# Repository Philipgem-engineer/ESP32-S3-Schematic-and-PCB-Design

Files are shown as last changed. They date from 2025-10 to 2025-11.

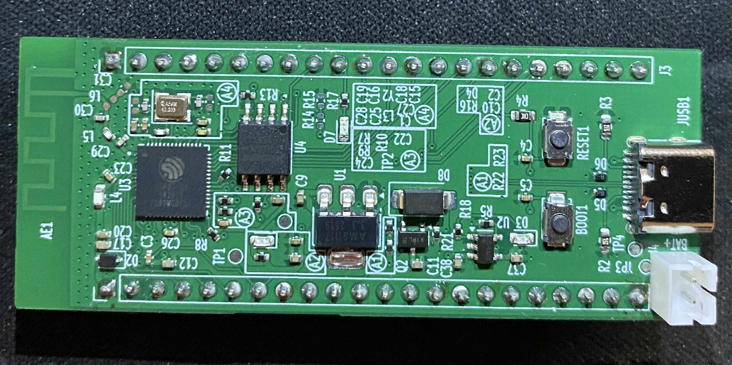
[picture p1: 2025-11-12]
ESP32-S3 Project/Media/ESP32-S3_Front_2.jpg

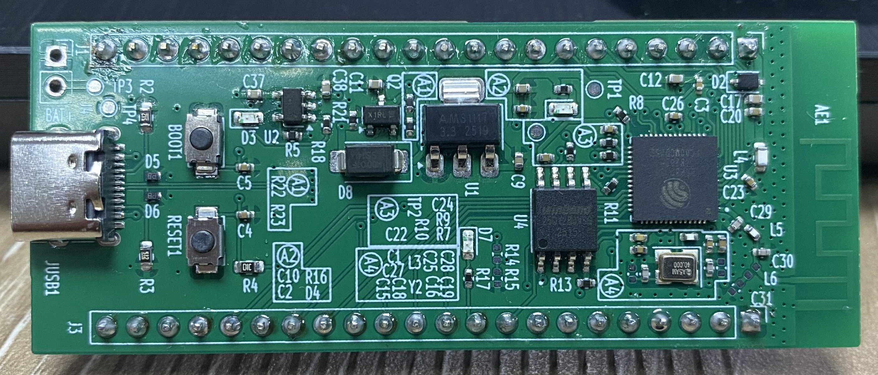
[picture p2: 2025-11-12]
ESP32-S3 Project/Media/ESP32-S3_Front.jpg

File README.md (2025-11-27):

# 🧠 ESP32-S3 – Schematic and PCB Design

This repository contains a custom hardware of an ESP32-S3 microcontroller dev board.
It includes the complete schematic and PCB layout, featuring essential supporting circuits.

##  Features
- ⚡ LDO Voltage Regulator – Provides a stable supply for the ESP32-S3 and peripherals
- 🔋 Battery Charging Circuit – Supports rechargeable lithium battery input
- 💾 Flash Memory – Enables program storage capacity
- 🧩 ESP32-S3 System-on-Chip – Dual-core processor with integrated Wi-Fi and Bluetooth
- ⏱️ Crystal Oscillator – Ensures precise clock timing for system stability
- 📡 Antenna & Antenna Matching Circuit – Integrated in PCB for Wi-Fi/Bluetooth connectivity

##  Tools Used
-  Schematic & PCB Design: KiCad
-  Component Library: LCSC
-  PCB Fabrication: JLCPCB

##  Schematic





##  PCB Design



##  PCB 3D view






##  Manufactured PCB
ESP32-S3_Front

## 📁 File Structure

<details>
  <summary>ESP32-S3 Project/</summary>
  <ul>
    <li>
      Media/
      <ul>
        <li>(PDF, Images and videos of prototype)</li>
      </ul>
    </li>
    <li>
      pcb/
      <ul>
        <li>(Gerber, BOM, Positions)</li>
      </ul>
    </li>
</details>

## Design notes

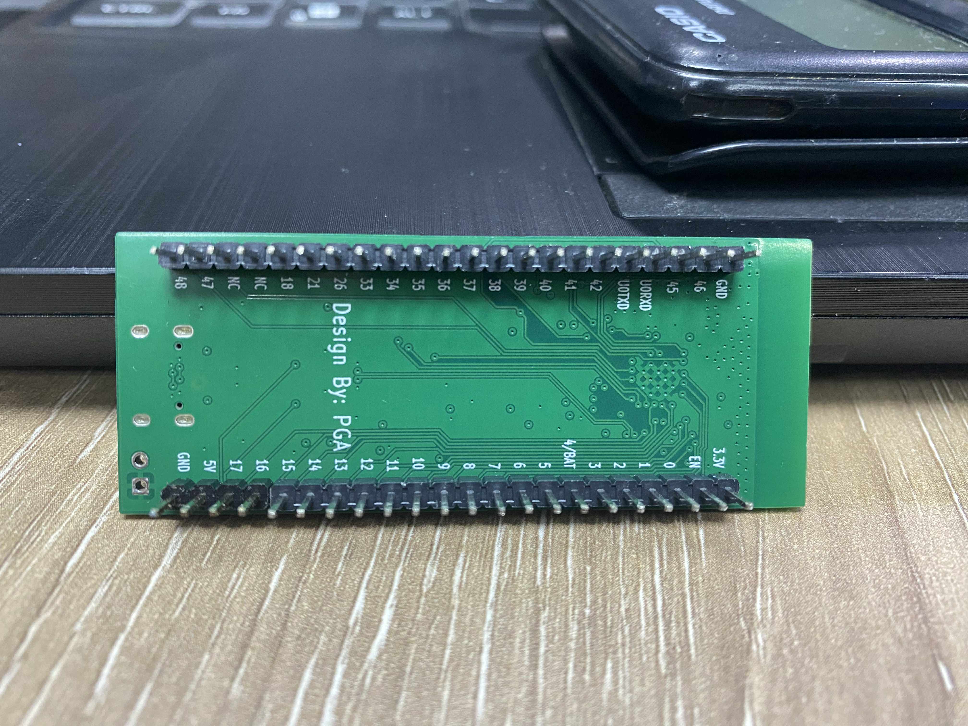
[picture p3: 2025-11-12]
ESP32-S3 Project/Media/ESP32-S3_Back.jpg

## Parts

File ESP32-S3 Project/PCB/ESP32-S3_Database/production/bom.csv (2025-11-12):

Designator | Footprint | Quantity | Value | LCSC Part #
AE1 | Texas_SWRA117D_2.4GHz_Left | 1 | Antenna_Chip
BOOT1, RESET1 | SW_TS-1088-AR02016 | 2 | TS-1088-AR02016 | TS-1088-AR02016
C1 | 0402 | 1 | 10 nF | CL05B103KB5NNNC
C10, C12, C9 | 0402 | 3 | 10uF | CL05A106MQ5NUNC
C11, C37, C38 | 0402 | 3 | 10uF | C15525
C16, C18 | 0402 | 2 | 22pF | 0402CG220J500NT
C17 | 0402 | 1 | 10uF | CL05A106MQ5NUNC
C2, C3 | 0402 | 2 | 0.1uF | CL05B104KO5NNNC
C20 | 0402 | 1 | 1uF | CL05A105KA5NQNC
C22, C28 | 0402 | 2 | 1uF | CL05A105KA5NQNC
C23, C24, C25, C26, C27 | 0402 | 5 | 0.1uF | CL05B104KO5NNNC
C29, C30 | 0402 | 2 | 15pF | 0402CG220J500NT
C4, C5 | 0402 | 2 | 0.1uF | CL05B104KO5NNNC
D2 | D_SOD-323 | 1 | ESD 3.3V | H3V3HD3B
D3 | 0603 | 1 | LED | C2286
D4, D7 | 0603 | 2 | LED | KT-0603R
D5, D6 | H5VL10B | 2 | ~ | H5VL10B
D8 | D_SMA | 1 | SS14 | C2480
J1, J3 | PinHeader_1x22_P2.54mm_Vertical | 2 | ~
J4 | PinSocket_1x02_P2.54mm_Vertical | 1 | Conn_01x02_Pin
JUSB1 | USB_TYPE_18 | 1 | ~ | DEALON USB-TYPE-C-018
L3 | 0402 | 1 | 24 nH | SDCL1005C24NJTDF
L4 | 0603 | 1 | 2 nH | SDCL1608C2N0STDF
L5 | 0402 | 1 | 4.7nH | SDCL1005C4N7STDF
Q2 | SOT-23 | 1 | AO3401A | C15127
R10, R11, R7, R8, R9 | 0402 | 5 | 0 | 0402WGF0000TCE
R13 | 0402 | 1 | 499 | 0402WGF4700TCE
R16, R17 | 0402 | 2 | 499 | 0402WGF4700TCE
R18 | 0402 | 1 | 1K | C11702
R2, R3 | 0603 | 2 | 5.1K | 0603WAF5101T5E
R21 | 0402 | 1 | 100K | C25741
R22, R23 | 0402 | 2 | 200K | C25764
R4 | 0603 | 1 | 10K | 0603WAF1002T5E
R5 | 0402 | 1 | 2K | C4109
TP1, TP2, TP3, TP4 | TestPoint_Pad_D1.0mm | 4 | TestPoint
U1 | SOT-223-3_TabPin2 | 1 | AMS1117-3.3 | AMS1117-3.3
U2 | SOT-23-5 | 1 | ~ | TP4054-42-SOT25R
U3 | IC_ESP32-S3 | 1 | ESP32-S3 | C2913192
U4 | SOIC127P790X216-8N | 1 | W25Q128JVSIQ | W25Q128JVSIQ
Y2 | Crystal_SMD_3225-4Pin_3.2x2.5mm | 1 | ~ | 5YMA40000151SF40E1

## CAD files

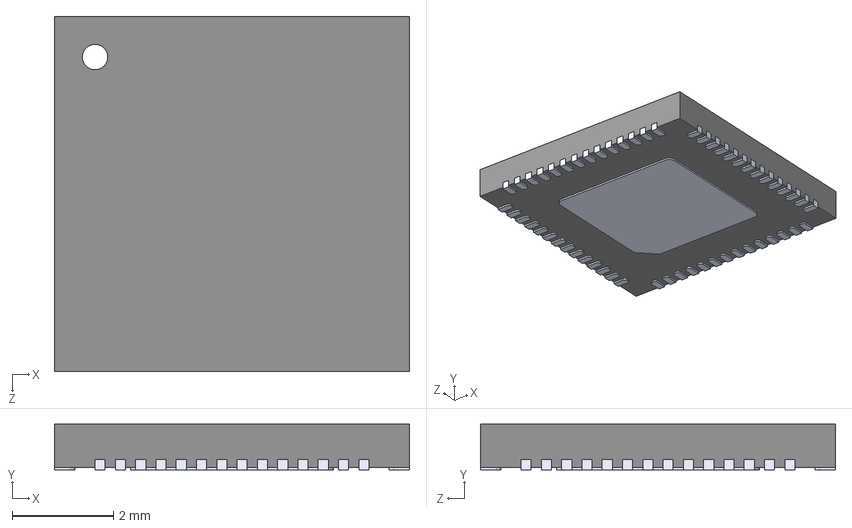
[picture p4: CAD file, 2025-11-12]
ESP32-S3 Project/PCB/ESP32-S3_Database/ESP32-S3.step
7.00 x 0.9 x 7.00 mm

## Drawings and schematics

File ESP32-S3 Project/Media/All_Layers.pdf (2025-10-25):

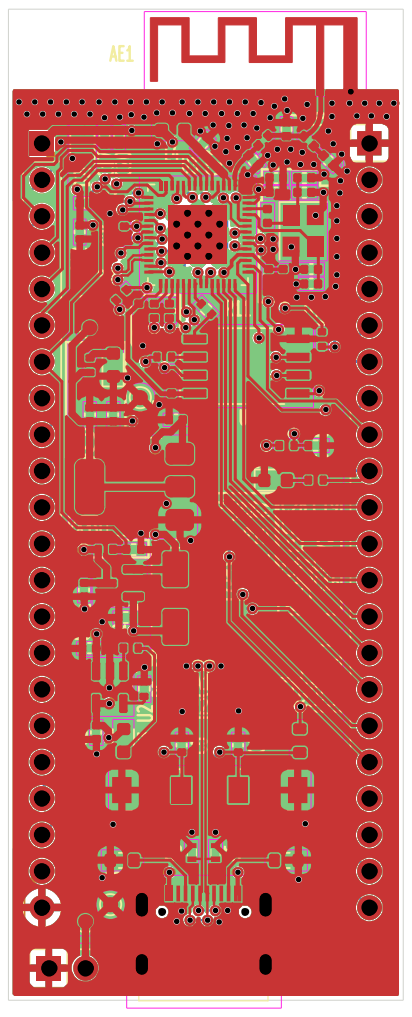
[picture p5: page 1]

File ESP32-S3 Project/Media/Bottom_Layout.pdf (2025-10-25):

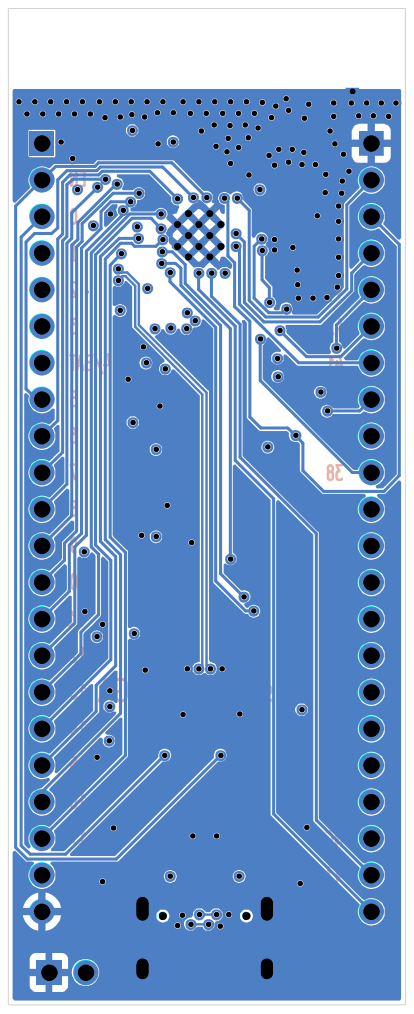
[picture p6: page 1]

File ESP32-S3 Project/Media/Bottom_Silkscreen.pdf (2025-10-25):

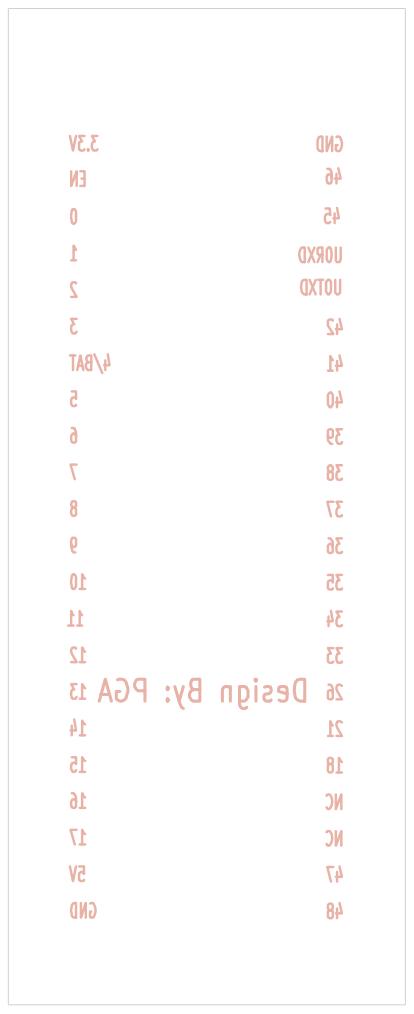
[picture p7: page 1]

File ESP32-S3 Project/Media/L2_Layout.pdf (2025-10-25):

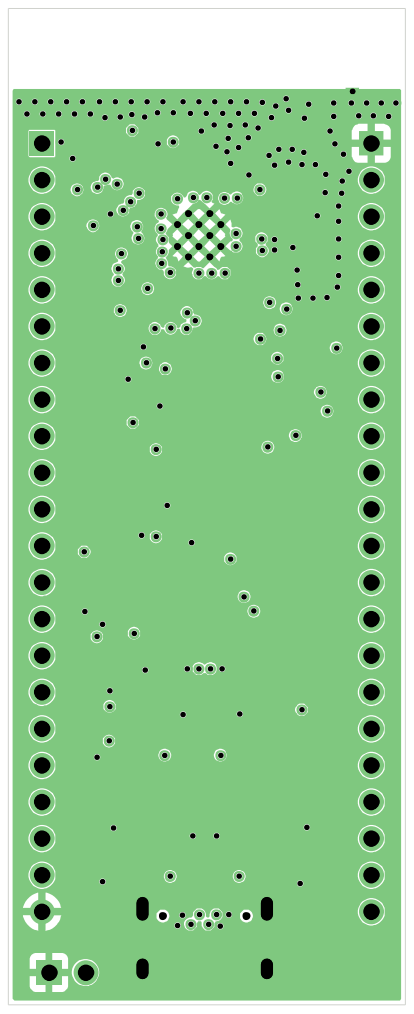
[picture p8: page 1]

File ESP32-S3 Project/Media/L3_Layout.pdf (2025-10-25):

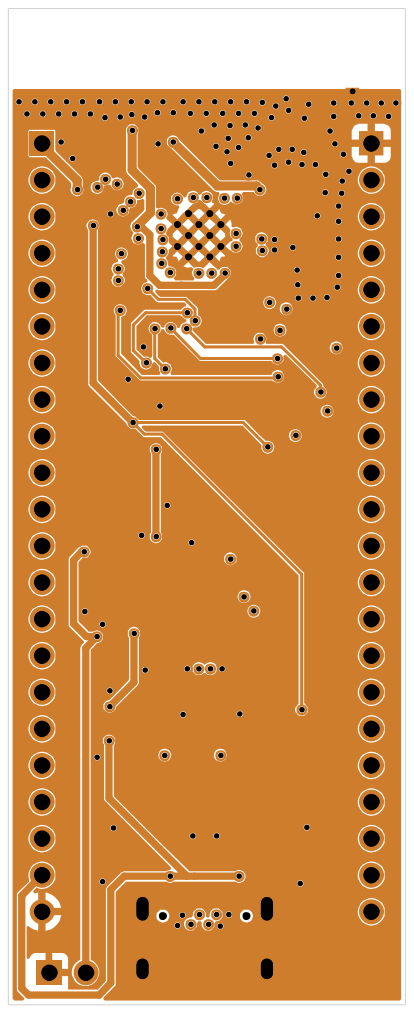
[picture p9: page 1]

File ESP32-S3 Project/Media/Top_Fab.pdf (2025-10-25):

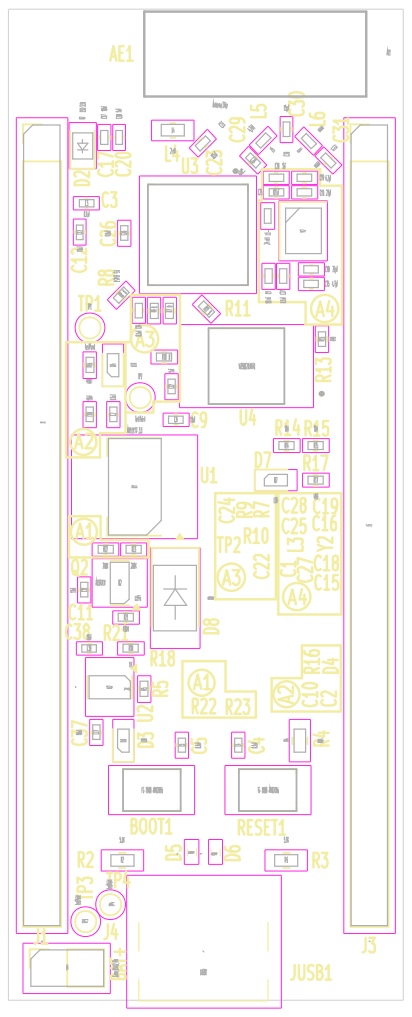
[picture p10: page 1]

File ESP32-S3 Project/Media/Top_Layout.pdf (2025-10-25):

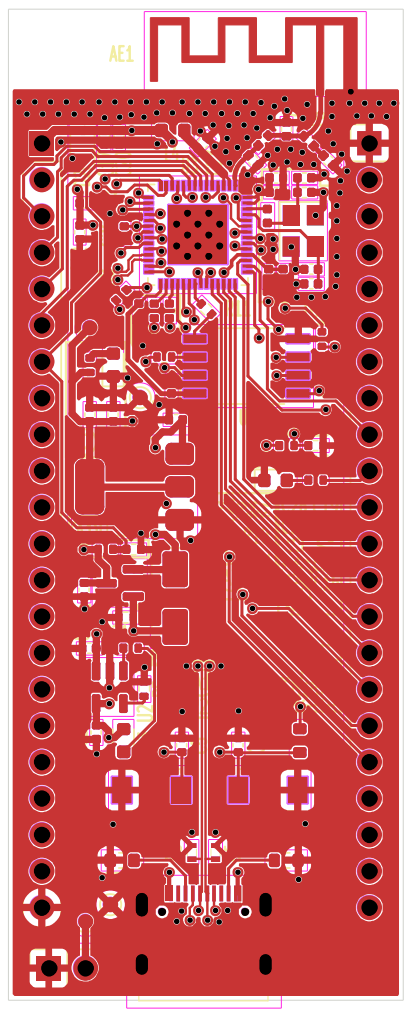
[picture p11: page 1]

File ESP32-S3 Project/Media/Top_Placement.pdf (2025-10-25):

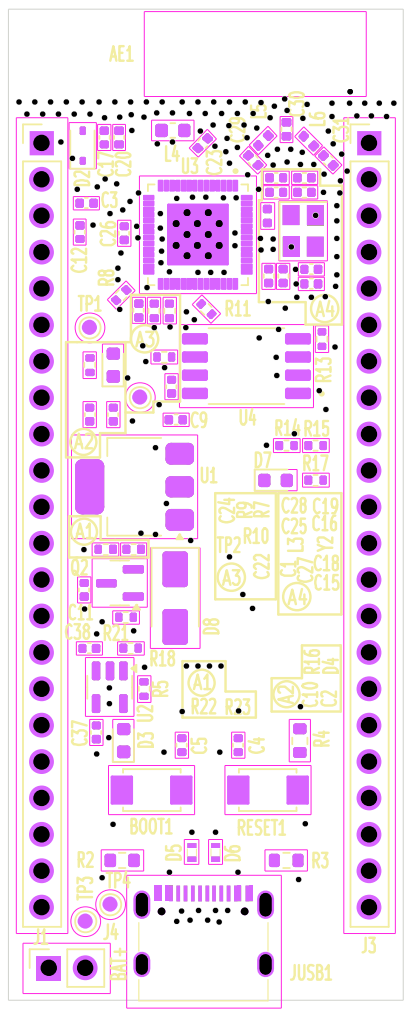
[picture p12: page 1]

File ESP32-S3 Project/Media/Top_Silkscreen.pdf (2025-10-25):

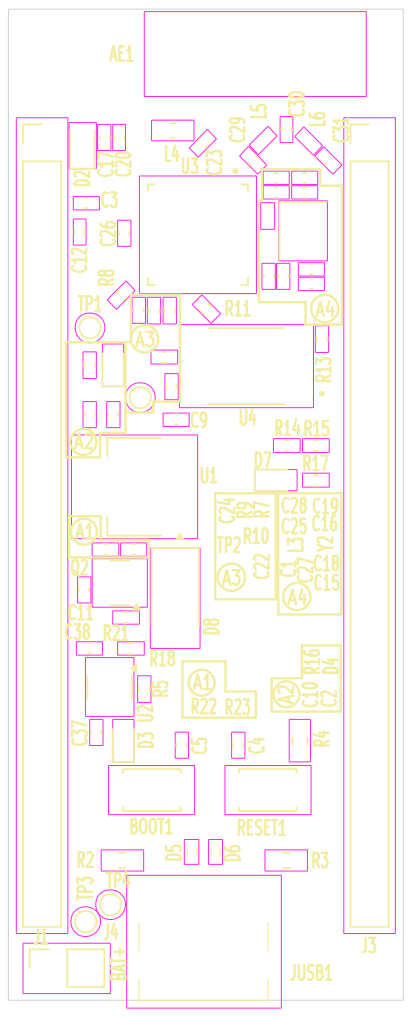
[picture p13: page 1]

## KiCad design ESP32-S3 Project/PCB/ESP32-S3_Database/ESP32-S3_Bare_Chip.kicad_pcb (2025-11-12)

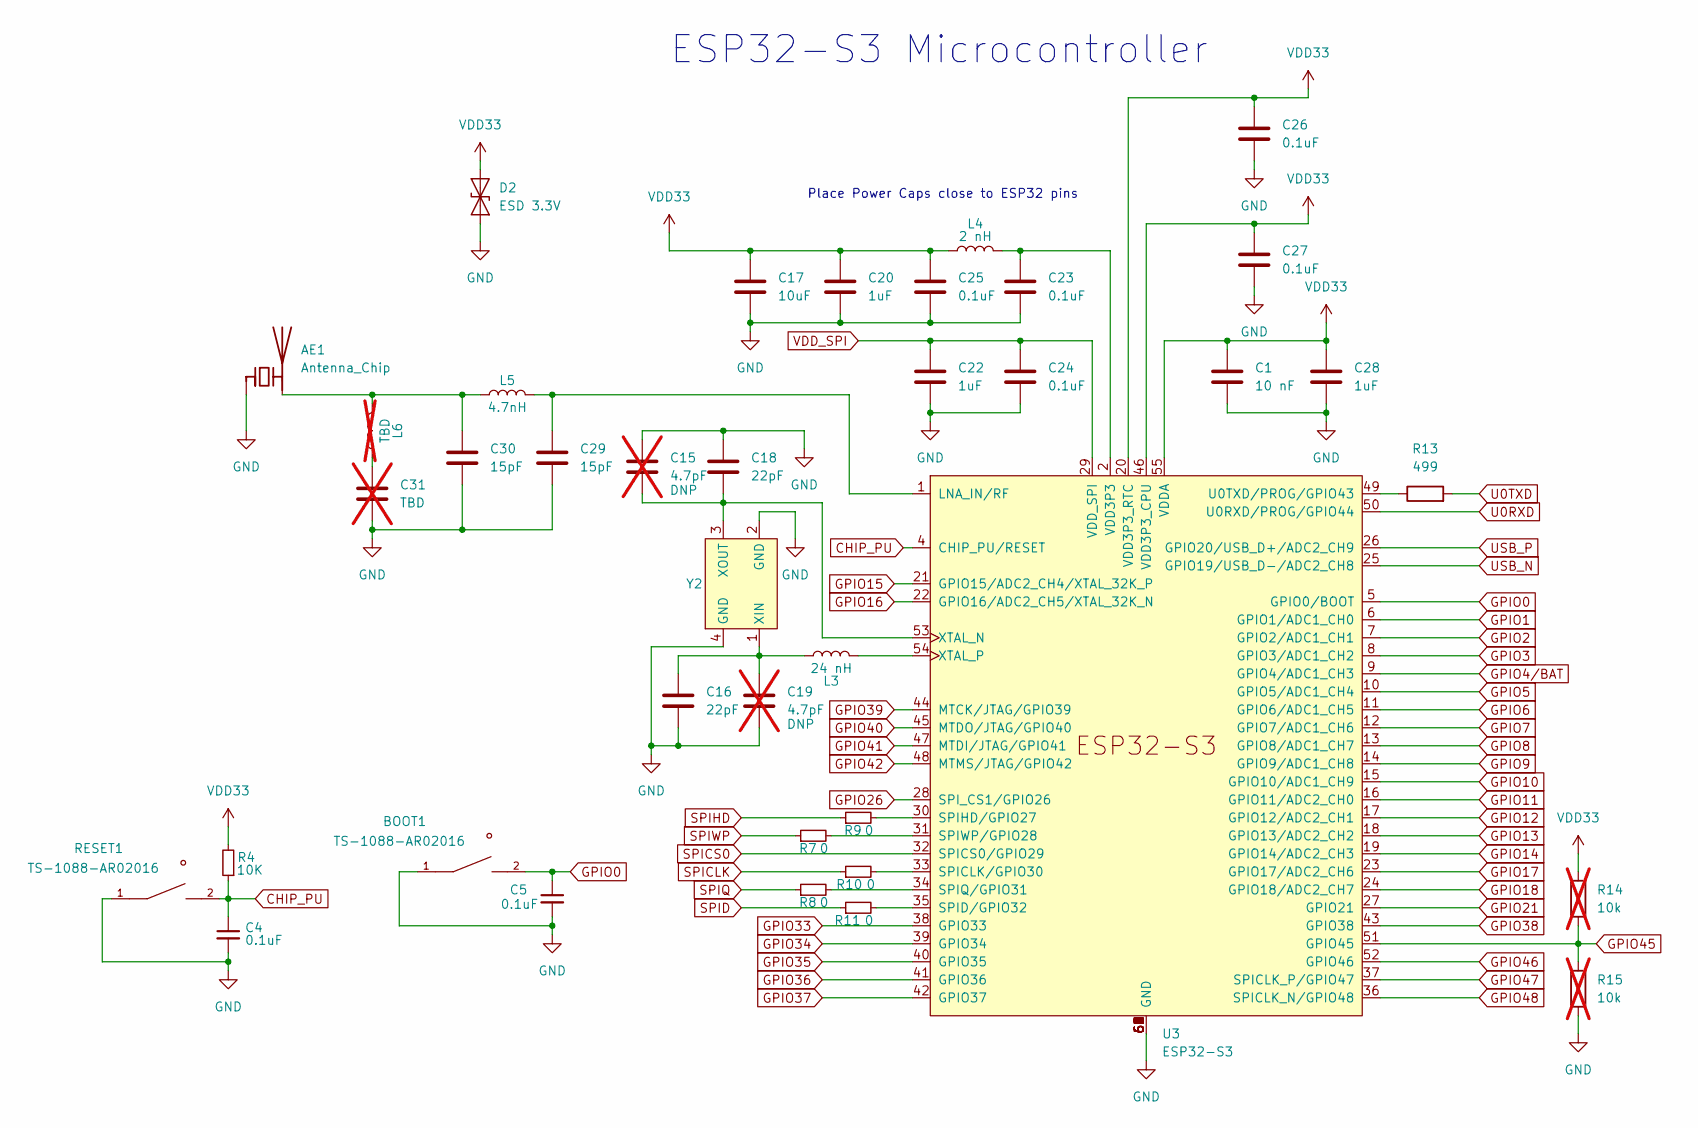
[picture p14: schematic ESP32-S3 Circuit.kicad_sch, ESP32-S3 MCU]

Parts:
AE1: Antenna_Chip; Texas_SWRA117D_2.4GHz_Left
BOOT1: TS-1088-AR02016; SW_TS-1088-AR02016; PARTREV N/A
C1: 10 nF; C_0402_1005Metric; MPN CL05B103KB5NNNC
C4, C5, C23, C24, C25, C26, C27: 0.1uF; C_0402_1005Metric; MPN CL05B104KO5NNNC
C15, C19: 4.7pF; C_0402_1005Metric; not fitted
C16, C18: 22pF; C_0402_1005Metric; MPN 0402CG220J500NT
C17: 10uF; C_0402_1005Metric; MPN CL05A106MQ5NUNC
C20, C22, C28: 1uF; C_0402_1005Metric; MPN CL05A105KA5NQNC
C29, C30: 15pF; C_0402_1005Metric; MPN 0402CG220J500NT
C31: TBD; C_0402_1005Metric; MPN 0402CG220J500NT; not fitted
D2: ESD 3.3V; D_SOD-323; MPN H3V3HD3B
L3: 24 nH; L_0402_1005Metric; MPN SDCL1005C24NJTDF
L4: 2 nH; L_0603_1608Metric; MPN SDCL1608C2N0STDF
L5: 4.7nH; L_0402_1005Metric; MPN SDCL1005C4N7STDF
L6: TBD; L_0402_1005Metric; not fitted
R4: 10K; R_0603_1608Metric; MPN 0603WAF1002T5E
R7, R8, R9, R10, R11: 0; R_0402_1005Metric; MPN 0402WGF0000TCE
R13: 499; R_0402_1005Metric; MPN 0402WGF4700TCE
R14, R15: 10k; R_0402_1005Metric; MPN 0402WGF1002TCE; not fitted
RESET1: TS-1088-AR02016; SW_TS-1088-AR02016; PARTREV N/A
U3: ESP32-S3; IC_ESP32-S3; MPN ESP32-S3; LCSC PN C2913192
Y2: Crystal_SMD_3225-4Pin_3.2x2.5mm; MPN 5YMA40000151SF40E1

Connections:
CHIP_PU: C4.1, R4.1, RESET1.2, U3.4 (CHIP_PU/RESET); also elsewhere on the board
GND: AE1.2 (FEED), BOOT1.1, C1.2, C4.2, C5.2, C15.1, C16.2, C17.2, C18.1, C19.2, C20.2, C22.2, C23.2, C24.2, C25.2, C26.2, C27.2, C28.2, C29.2, C30.2, C31.2, D2.1 (A1), R15.1, RESET1.1, U3.57 (GND), U3.58 (GND), U3.59 (GND), U3.60 (GND), U3.61 (GND), U3.62 (GND), U3.63 (GND), U3.64 (GND), U3.65 (GND), U3.66 (GND), U3.67 (GND), U3.68 (GND), U3.69 (GND), Y2.2 (GND), Y2.4 (GND); also elsewhere on the board
GPIO0: BOOT1.2, C5.1, U3.5 (GPIO0/BOOT); also elsewhere on the board
GPIO1: U3.6 (GPIO1/ADC1_CH0); also elsewhere on the board
GPIO2: U3.7 (GPIO2/ADC1_CH1); also elsewhere on the board
GPIO3: U3.8 (GPIO3/ADC1_CH2); also elsewhere on the board
GPIO4/BAT: U3.9 (GPIO4/ADC1_CH3); also elsewhere on the board
GPIO5: U3.10 (GPIO5/ADC1_CH4); also elsewhere on the board
GPIO6: U3.11 (GPIO6/ADC1_CH5); also elsewhere on the board
GPIO7: U3.12 (GPIO7/ADC1_CH6); also elsewhere on the board
GPIO8: U3.13 (GPIO8/ADC1_CH7); also elsewhere on the board
GPIO9: U3.14 (GPIO9/ADC1_CH8); also elsewhere on the board
GPIO10: U3.15 (GPIO10/ADC1_CH9); also elsewhere on the board
GPIO11: U3.16 (GPIO11/ADC2_CH0); also elsewhere on the board
GPIO12: U3.17 (GPIO12/ADC2_CH1); also elsewhere on the board
GPIO13: U3.18 (GPIO13/ADC2_CH2); also elsewhere on the board
GPIO14: U3.19 (GPIO14/ADC2_CH3); also elsewhere on the board
GPIO15: U3.21 (GPIO15/ADC2_CH4/XTAL_32K_P); also elsewhere on the board
GPIO16: U3.22 (GPIO16/ADC2_CH5/XTAL_32K_N); also elsewhere on the board
GPIO17: U3.23 (GPIO17/ADC2_CH6); also elsewhere on the board
GPIO18: U3.24 (GPIO18/ADC2_CH7); also elsewhere on the board
GPIO21: U3.27 (GPIO21); also elsewhere on the board
GPIO26: U3.28 (SPI_CS1/GPIO26); also elsewhere on the board
GPIO33: U3.38 (GPIO33); also elsewhere on the board
GPIO34: U3.39 (GPIO34); also elsewhere on the board
GPIO35: U3.40 (GPIO35); also elsewhere on the board
GPIO36: U3.41 (GPIO36); also elsewhere on the board
GPIO37: U3.42 (GPIO37); also elsewhere on the board
GPIO38: U3.43 (GPIO38); also elsewhere on the board
GPIO39: U3.44 (MTCK/JTAG/GPIO39); also elsewhere on the board
GPIO40: U3.45 (MTDO/JTAG/GPIO40); also elsewhere on the board
GPIO41: U3.47 (MTDI/JTAG/GPIO41); also elsewhere on the board
GPIO42: U3.48 (MTMS/JTAG/GPIO42); also elsewhere on the board
GPIO45: R14.1, R15.2, U3.51 (GPIO45); also elsewhere on the board
GPIO46: U3.52 (GPIO46); also elsewhere on the board
GPIO47: U3.37 (SPICLK_P/GPIO47); also elsewhere on the board
GPIO48: U3.36 (SPICLK_N/GPIO48); also elsewhere on the board
unnamed: AE1.1 (PCB_Trace), C30.1, L5.1, L6.2
unnamed: C31.1, L6.1
unnamed: C29.1, L5.2, U3.1 (LNA_IN/RF)
unnamed: R10.2, U3.33 (SPICLK/GPIO30)
unnamed: R11.2, U3.35 (SPID/GPIO32)
unnamed: R9.2, U3.30 (SPIHD/GPIO27)
unnamed: R8.2, U3.34 (SPIQ/GPIO31)
unnamed: R7.2, U3.31 (SPIWP/GPIO28)
unnamed: R13.1, U3.49 (U0TXD/PROG/GPIO43)
unnamed: C15.2, C18.2, U3.53 (XTAL_N), Y2.3 (XOUT)
unnamed: L3.2, U3.54 (XTAL_P)
unnamed: C16.1, C19.1, L3.1, Y2.1 (XIN)
SPICLK: R10.1; also elsewhere on the board
SPICS0: U3.32 (SPICS0/GPIO29); also elsewhere on the board
SPID: R11.1; also elsewhere on the board
SPIHD: R9.1; also elsewhere on the board
SPIQ: R8.1; also elsewhere on the board
SPIWP: R7.1; also elsewhere on the board
U0RXD: U3.50 (U0RXD/PROG/GPIO44); also elsewhere on the board
U0TXD: R13.2; also elsewhere on the board
USB_N: U3.25 (GPIO19/USB_D-/ADC2_CH8); also elsewhere on the board
USB_P: U3.26 (GPIO20/USB_D+/ADC2_CH9); also elsewhere on the board
VDD3P3: C23.1, L4.2, U3.2 (VDD3P3), U3.3 (VDD3P3)
VDD33: C1.1, C17.1, C20.1, C25.1, C26.1, C27.1, C28.1, D2.2 (A2), L4.1, R4.2, R14.2, U3.20 (VDD3P3_RTC), U3.46 (VDD3P3_CPU), U3.55 (VDDA), U3.56 (VDDA); also elsewhere on the board
VDD_SPI: C22.1, C24.1, U3.29 (VDD_SPI); also elsewhere on the board

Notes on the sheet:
Place Power Caps close to ESP32 pins
ESP32-S3 Microcontroller

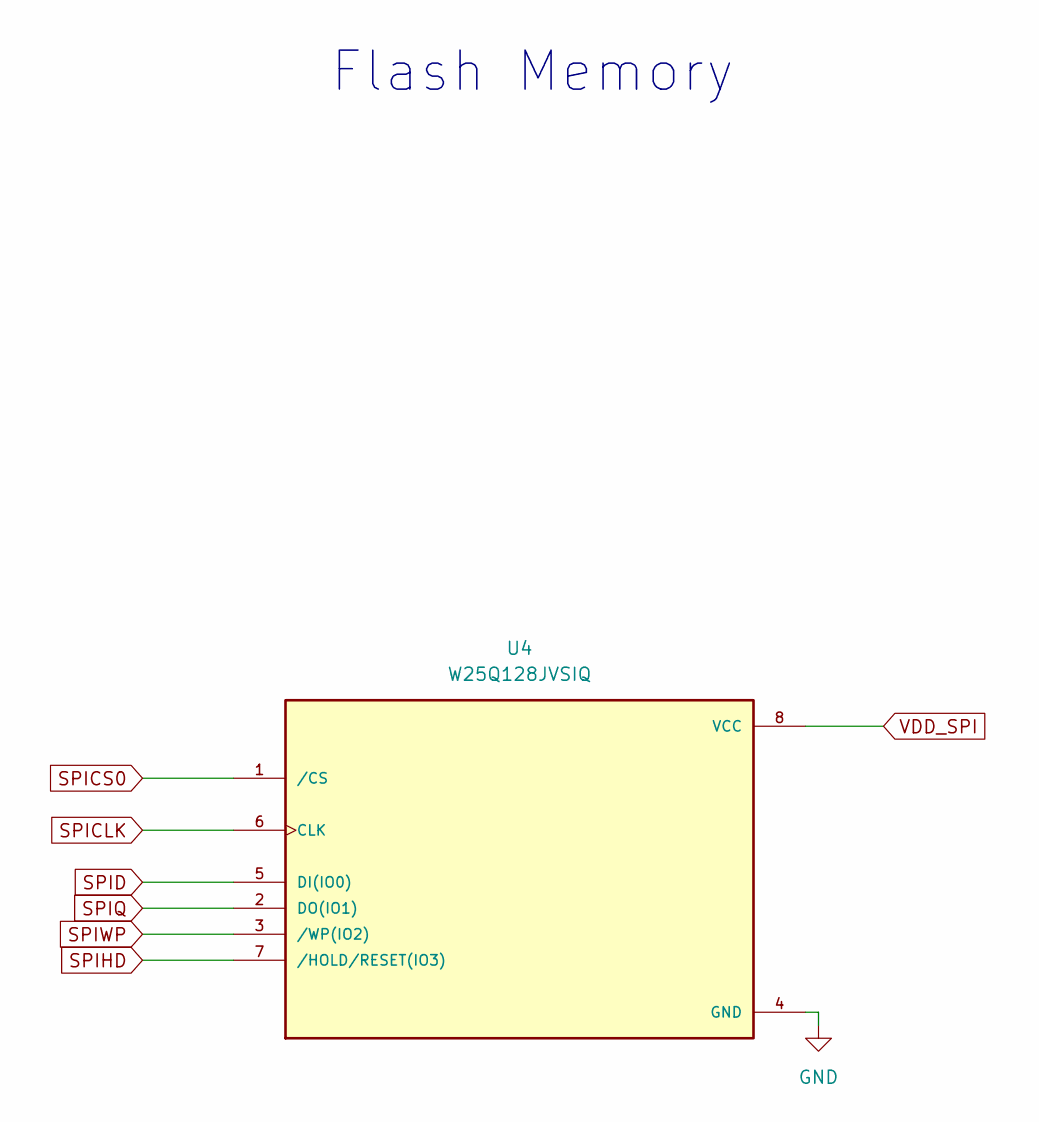
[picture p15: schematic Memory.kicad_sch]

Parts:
U4: W25Q128JVSIQ; SOIC127P790X216-8N; PARTREV I

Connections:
GND: U4.4 (GND); also elsewhere on the board
SPICLK: U4.6 (CLK); also elsewhere on the board
SPICS0: U4.1 (/CS); also elsewhere on the board
SPID: U4.5 (DI(IO0)); also elsewhere on the board
SPIHD: U4.7 (/HOLD/RESET(IO3)); also elsewhere on the board
SPIQ: U4.2 (DO(IO1)); also elsewhere on the board
SPIWP: U4.3 (/WP(IO2)); also elsewhere on the board
VDD_SPI: U4.8 (VCC); also elsewhere on the board

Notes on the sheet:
Flash Memory

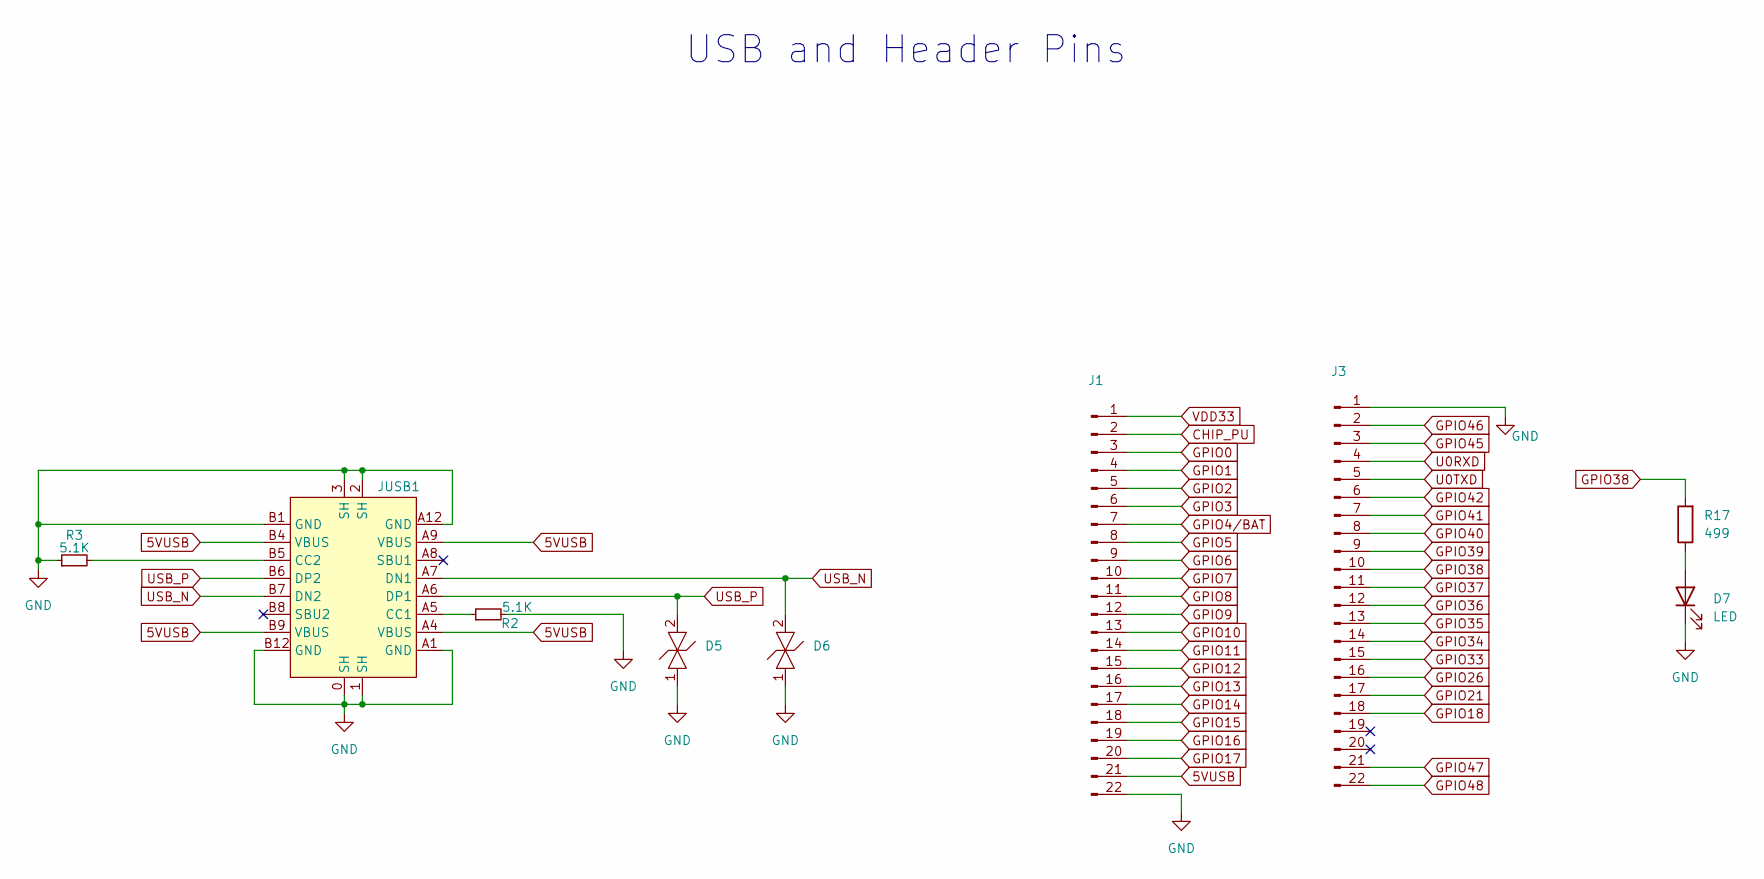
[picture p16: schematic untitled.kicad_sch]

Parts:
D5, D6: H5VL10B; MPN H5VL10B
D7: LED; LED_0603_1608Metric; MPN KT-0603R
J1, J3: PinHeader_1x22_P2.54mm_Vertical
JUSB1: USB_TYPE_18; MPN DEALON USB-TYPE-C-018
R2, R3: 5.1K; R_0603_1608Metric; MPN 0603WAF5101T5E
R17: 499; R_0402_1005Metric; MPN 0402WGF4700TCE

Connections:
5VUSB: J1.21, JUSB1.A4 (VBUS), JUSB1.A9 (VBUS), JUSB1.B4 (VBUS), JUSB1.B9 (VBUS); also elsewhere on the board
CHIP_PU: J1.2; also elsewhere on the board
GND: D5.1, D6.1, D7.1 (K), J1.22, J3.1, JUSB1.0 (SH), JUSB1.1 (SH), JUSB1.2 (SH), JUSB1.3 (SH), JUSB1.A1 (GND), JUSB1.A12 (GND), JUSB1.B1 (GND), JUSB1.B12 (GND), R2.2, R3.1; also elsewhere on the board
GPIO0: J1.3; also elsewhere on the board
GPIO1: J1.4; also elsewhere on the board
GPIO2: J1.5; also elsewhere on the board
GPIO3: J1.6; also elsewhere on the board
GPIO4/BAT: J1.7; also elsewhere on the board
GPIO5: J1.8; also elsewhere on the board
GPIO6: J1.9; also elsewhere on the board
GPIO7: J1.10; also elsewhere on the board
GPIO8: J1.11; also elsewhere on the board
GPIO9: J1.12; also elsewhere on the board
GPIO10: J1.13; also elsewhere on the board
GPIO11: J1.14; also elsewhere on the board
GPIO12: J1.15; also elsewhere on the board
GPIO13: J1.16; also elsewhere on the board
GPIO14: J1.17; also elsewhere on the board
GPIO15: J1.18; also elsewhere on the board
GPIO16: J1.19; also elsewhere on the board
GPIO17: J1.20; also elsewhere on the board
GPIO18: J3.18; also elsewhere on the board
GPIO21: J3.17; also elsewhere on the board
GPIO26: J3.16; also elsewhere on the board
GPIO33: J3.15; also elsewhere on the board
GPIO34: J3.14; also elsewhere on the board
GPIO35: J3.13; also elsewhere on the board
GPIO36: J3.12; also elsewhere on the board
GPIO37: J3.11; also elsewhere on the board
GPIO38: J3.10, R17.2; also elsewhere on the board
GPIO39: J3.9; also elsewhere on the board
GPIO40: J3.8; also elsewhere on the board
GPIO41: J3.7; also elsewhere on the board
GPIO42: J3.6; also elsewhere on the board
GPIO45: J3.3; also elsewhere on the board
GPIO46: J3.2; also elsewhere on the board
GPIO47: J3.21; also elsewhere on the board
GPIO48: J3.22; also elsewhere on the board
unnamed: D7.2 (A), R17.1
unnamed: JUSB1.A5 (CC1), R2.1
unnamed: JUSB1.B5 (CC2), R3.2
U0RXD: J3.4; also elsewhere on the board
U0TXD: J3.5; also elsewhere on the board
USB_N: D6.2, JUSB1.A7 (DN1), JUSB1.B7 (DN2); also elsewhere on the board
USB_P: D5.2, JUSB1.A6 (DP1), JUSB1.B6 (DP2); also elsewhere on the board
VDD33: J1.1; also elsewhere on the board

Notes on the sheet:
USB and Header Pins

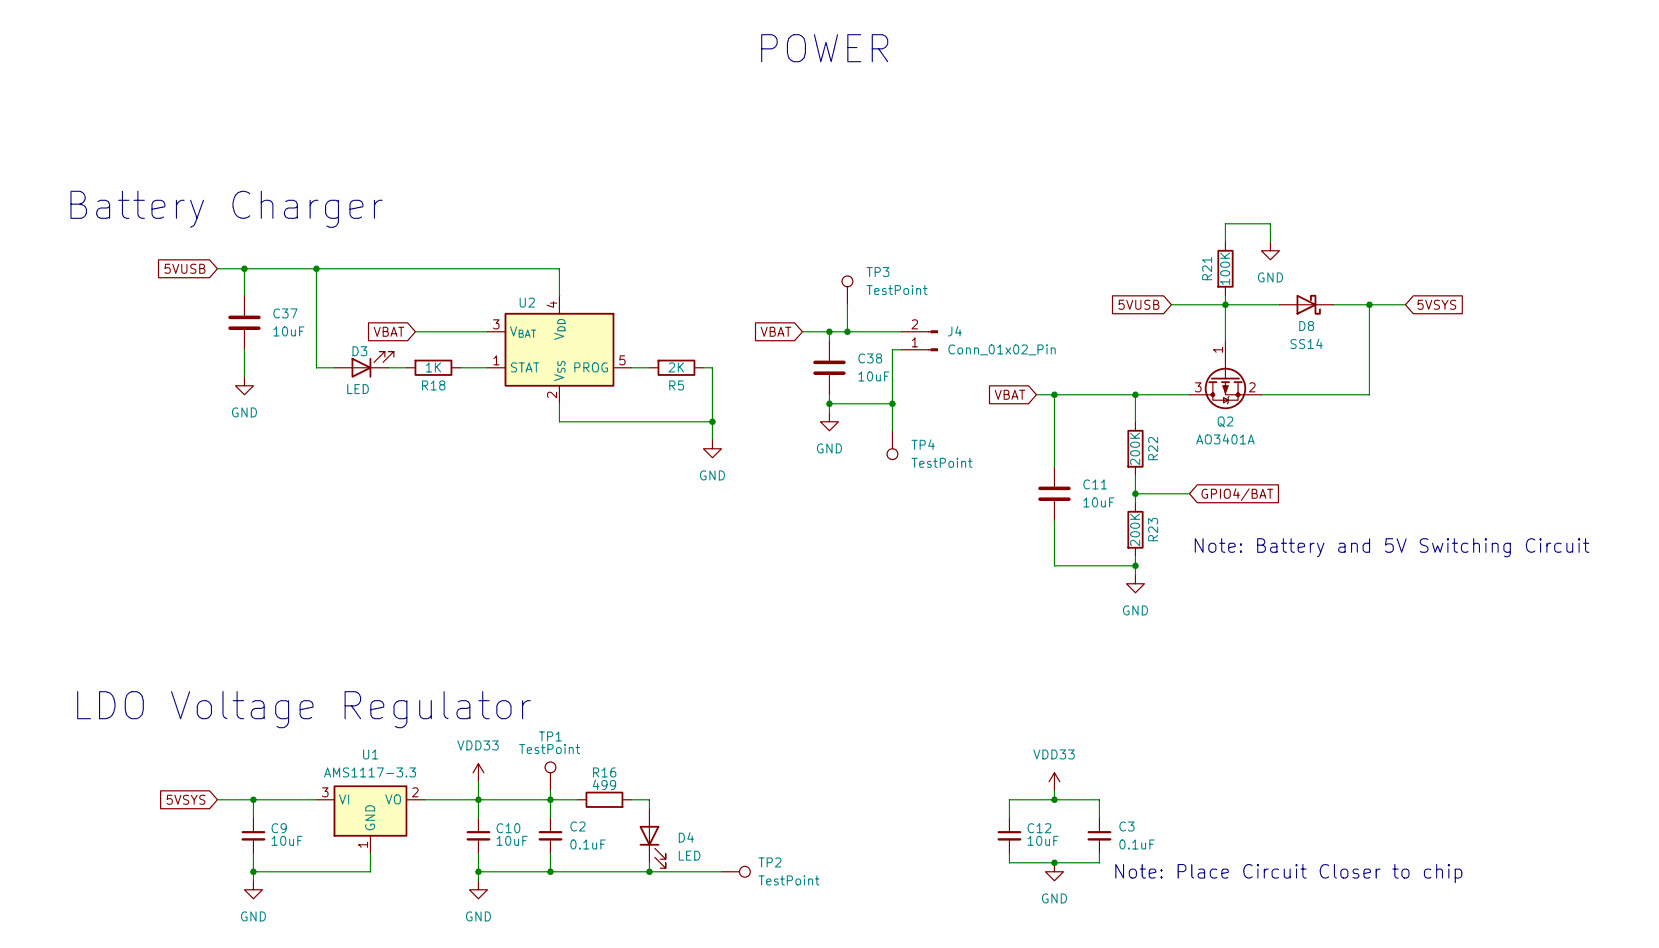
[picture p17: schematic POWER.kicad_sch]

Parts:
C2, C3: 0.1uF; C_0402_1005Metric; MPN CL05B104KO5NNNC
C9, C10, C12: 10uF; C_0402_1005Metric; MPN CL05A106MQ5NUNC
C11, C37, C38: 10uF; C_0402_1005Metric; MNF PART NUMBER C15525; LCSC C15525
D3: LED; LED_0603_1608Metric; MNF PART NUMBER C2286; LCSC C2286
D4: LED; LED_0603_1608Metric; MPN KT-0603R
D8: SS14; D_SMA; MNF PART NUMBER C2480; LCSC C2480
J4: Conn_01x02_Pin; PinSocket_1x02_P2.54mm_Vertical
Q2: AO3401A; SOT-23; MNF PART NUMBER C15127; LCSC C15127
R5: 2K; R_0402_1005Metric; MNF PART NUMBER C4109; LCSC C4109
R16: 499; R_0402_1005Metric; MPN 0402WGF4700TCE
R18: 1K; R_0402_1005Metric; MNF PART NUMBER C11702; LCSC C11702
R21: 100K; R_0402_1005Metric; MNF PART NUMBER C25741; LCSC C25741
R22, R23: 200K; R_0402_1005Metric; MNF PART NUMBER C25764; LCSC C25764
TP1, TP2, TP3, TP4: TestPoint; TestPoint_Pad_D1.0mm
U1: AMS1117-3.3; SOT-223-3_TabPin2; MPN AMS1117-3.3
U2: SOT-23-5; MPN TP4054-42-SOT25R

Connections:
5VSYS: C9.1, D8.1 (K), Q2.2 (S), U1.3 (VI)
5VUSB: C37.1, D3.2 (A), D8.2 (A), Q2.1 (G), R21.2, U2.4 (V_{DD}); also elsewhere on the board
GND: C2.2, C3.2, C9.2, C10.2, C11.2, C12.2, C37.2, C38.2, D4.1 (K), J4.1, R5.1, R21.1, R23.2, TP2.1, TP4.1, U1.1 (GND), U2.2 (V_{SS}); also elsewhere on the board
GPIO4/BAT: R22.2, R23.1; also elsewhere on the board
unnamed: D3.1 (K), R18.2
unnamed: D4.2 (A), R16.2
unnamed: R5.2, U2.5 (PROG)
unnamed: R18.1, U2.1 (STAT)
VBAT: C11.1, C38.1, J4.2, Q2.3 (D), R22.1, TP3.1, U2.3 (V_{BAT})
VDD33: C2.1, C3.1, C10.1, C12.1, R16.1, TP1.1, U1.2 (VO); also elsewhere on the board

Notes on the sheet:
LDO Voltage Regulator
Note: Place Circuit Closer to chip
Note: Battery and 5V Switching Circuit
POWER
Battery Charger

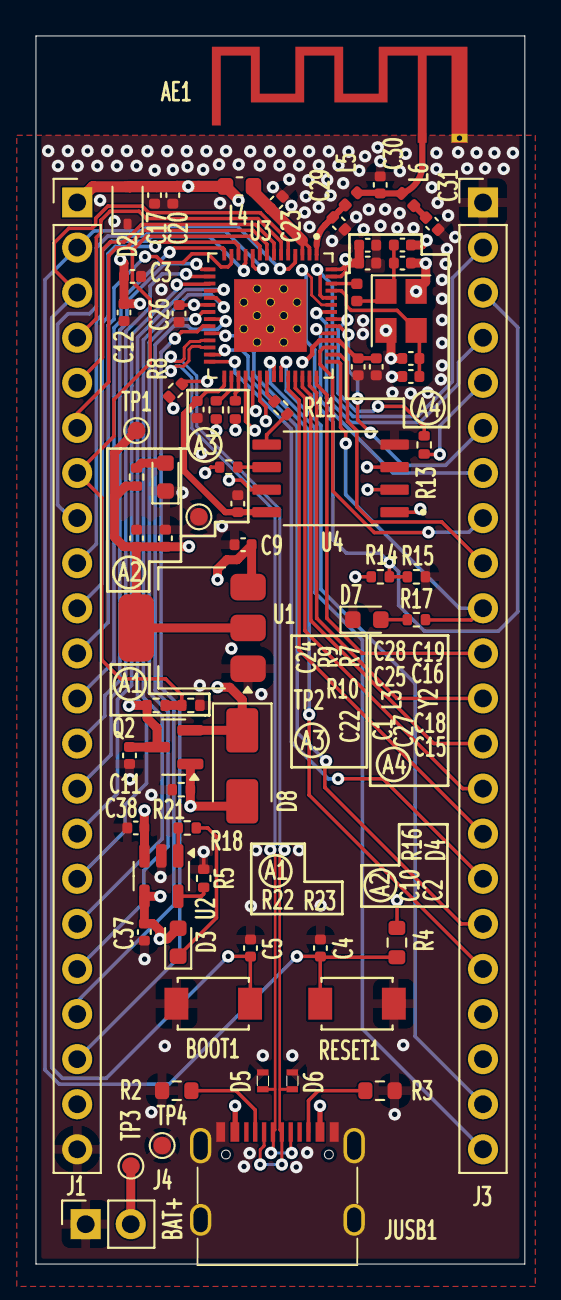
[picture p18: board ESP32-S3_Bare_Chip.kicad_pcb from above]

Board: 4 copper layers, 27.5 x 69.2 mm, 73 parts (0 on the bottom side), 72 nets.
